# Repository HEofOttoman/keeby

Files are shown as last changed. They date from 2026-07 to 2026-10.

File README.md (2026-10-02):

<!-- # Kai-Board v1
Custom 65% compact keyboard made by I, Henry Wauzivuff. -->
<header align="center">
<h1>Kai-Board v1</h1>
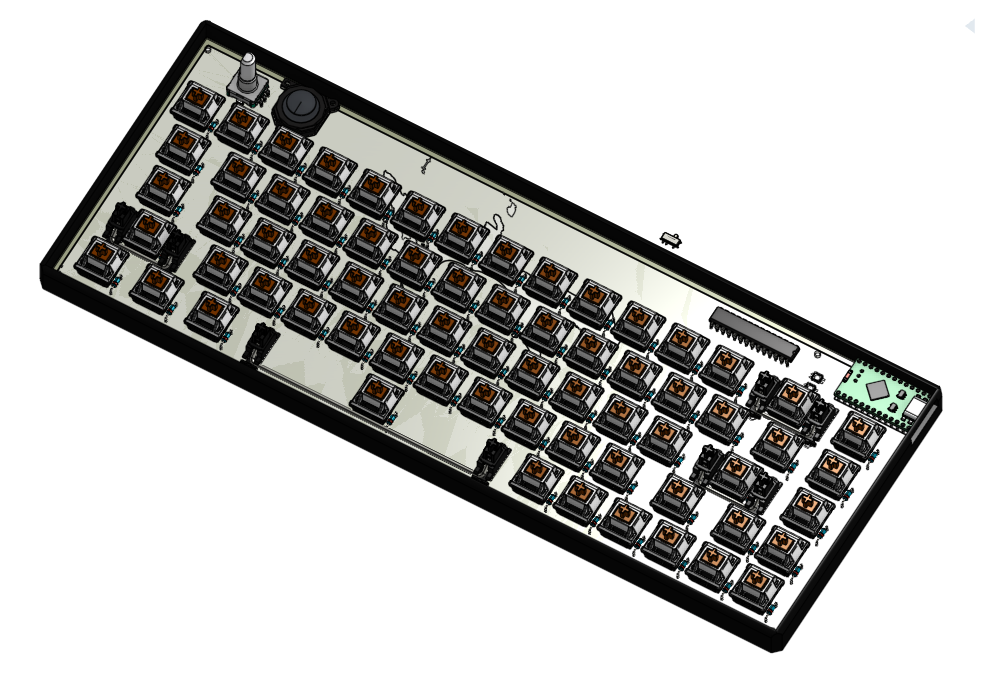
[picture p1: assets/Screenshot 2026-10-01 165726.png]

<h4>Custom wireless 65% compact keyboard made by Henry Wauzivuff.</h4>
</header>

## Features
- Wireless potential + Rechargable battery slot
- 65% compact
- Joystick (my replacement of the Thinkpad trackball)
- 1x EC11 Rotary Encoder

In a future design, I hope to include a usb hub, on/off switches, LEDs & whatever makes better use of the IO expander I ended up using

## Images

### Schematic
(outdated)

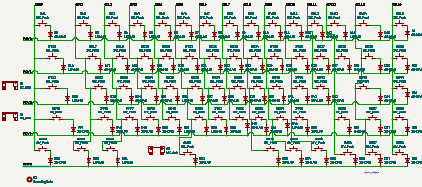
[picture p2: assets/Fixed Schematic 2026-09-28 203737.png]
and now, this works!!


### PCB
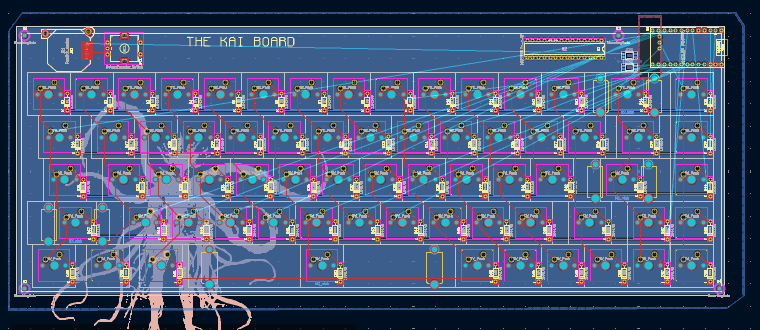
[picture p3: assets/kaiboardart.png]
art thing first


### CAD
Onshape link that may or may not [work](https://cad.onshape.com/documents/7e4f9e7530ad3774807d336c/w/6a2b4c794cd4ebe03f2424c9/e/2e40ded4774df0623cc9d47f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)
cad1

## BOM
|Qty|Item|Description|Cost (AUD/USD)|Link
|---|---|---|---|---|
|67x|MX Switches|Keys|||
|67x|1N4148|Diodes|||
|1x|Keycap Set|||
|1x|PCB||$$|
|1x|Case|housing duh|$|
|1x|PSP1000|Joystick maybe||
|2x|2.25u MX Stabilisers|||
|1x|6.25u MX Stabiliser|Spacebar|
|1x|2u MX Stabiliser|Backspace|
|1x|301230|Lipo Battery 500mAh|$2 (possible scam)|[aliexpress](https://www.aliexpress.com/item/32732458079.html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)|
|1x|MCP23017-SP GPIO Expanders||||

## References
Useful Links
- https://github.com/joric/nrfmicro/wiki
- https://github.com/RafaelCasamaximo/voidPointer
- https://github.com/ebastler/marbastlib (plugin & content manager)
- https://github.com/joric/nrfmicro/wiki/Pinout - Pinout, might be useful idk
- https://github.com/joric/nrfmicro/wiki/Alternatives/

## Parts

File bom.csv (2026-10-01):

Id | Designator | Footprint | Quantity | Designation | Supplier and ref
1 | D1, D2, D3, D4, D5, D6, D7, D8, D9, D10, D11, D12, D13, D14, D15, D16, D17, D18, D19, D20, D21, D22, D23, D24, D25, D26, D27, D28, D29, D30, D31, D32, D33, D34, D35, D36, D37, D38, D39, D40, D41, D42, D43, D44, D45, D46, D47, D48, D49, D50, D51, D52, D53, D54, D55, D56, D57, D58, D59, D60, D61, D62, D63, D64, D65, D66, D67, D68 | D_DO-35_SOD27_P7.62mm_Horizontal | 68 | 1N4148
2 | EC1 | ROT_Alps_EC11E-Switch | 1 | RotaryEncoder_Switch
3 | JS1 | PNT_psp1000 | 1 | joystick_analog
4 | LED1, LED2 | LED_SK6812MINI-E_3.2x2.8mm_P1.5mm_ReverseMount | 2 | SK6812MINI-E
5 | REF** | SW_MSK12C02-HB | 1 | SW_MSK12C02-HB
6 | S1, S3 | STAB_MX_2.25u | 2 | MX_stab
7 | S2 | STAB_MX_2u | 1 | MX_stab
8 | S4 | STAB_MX_6.25u | 1 | MX_stab
9 | SW1, SW2, SW3, SW4, SW5, SW6, SW7, SW8, SW9, SW10, SW11, SW12, SW13, SW14, SW15, SW16, SW17, SW18, SW19, SW20, SW21, SW22, SW23, SW24, SW25, SW26, SW27, SW28, SW29, SW30, SW31, SW32, SW33, SW34, SW35, SW36, SW37, SW38, SW39, SW40, SW41, SW42, SW43, SW44, SW45, SW46, SW47, SW48, SW49, SW50, SW51, SW52, SW53, SW54, SW55, SW56, SW57, SW58, SW59, SW60, SW61, SW62, SW63, SW64, SW65, SW66, SW67, SW68 | SW_MX_1u | 68 | SW_Push
10 | U2 | DIP-28_W7.62mm | 1 | MCP23017x-x-SP

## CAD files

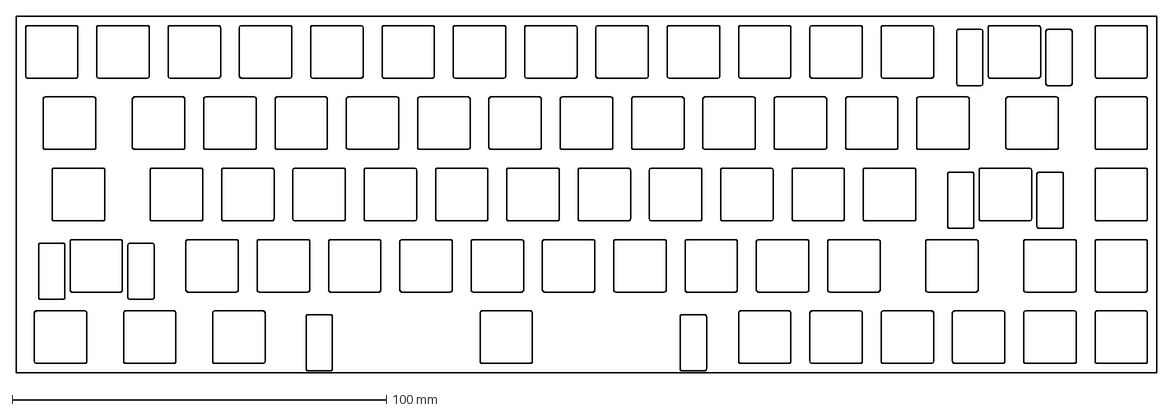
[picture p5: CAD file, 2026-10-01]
65%compact.dxf
304.8 x 95.2 mm

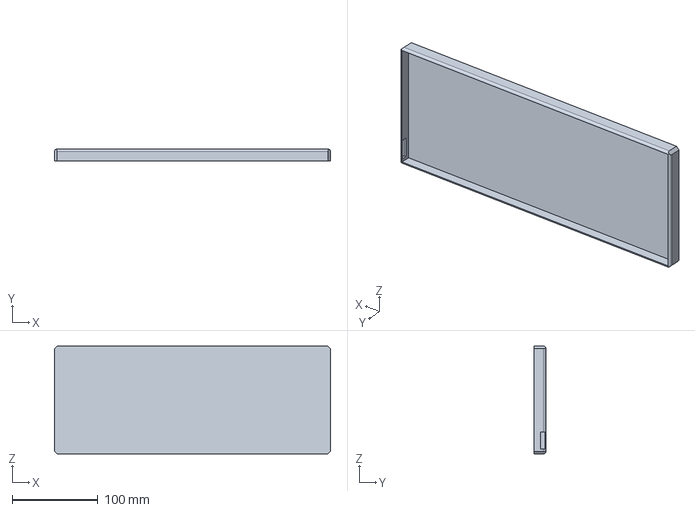
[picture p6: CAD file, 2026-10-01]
cad/Kai Board Case Base.step
321.0 x 13.5 x 125.5 mm

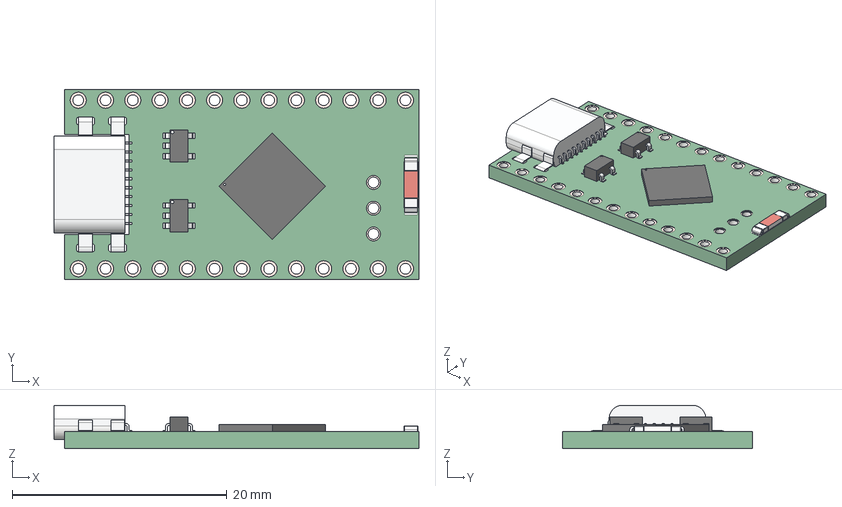
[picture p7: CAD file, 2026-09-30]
cad/nrf52840-1.snapshot.8/ProMicro NRF52840 AUYXSSZ.step
34.0 x 17.7 x 4.05 mm

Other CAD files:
cad/pcb v000.step
cad/nrf52840-1.snapshot.8/ProMicro NRF52840 AUYXSSZ.f3d

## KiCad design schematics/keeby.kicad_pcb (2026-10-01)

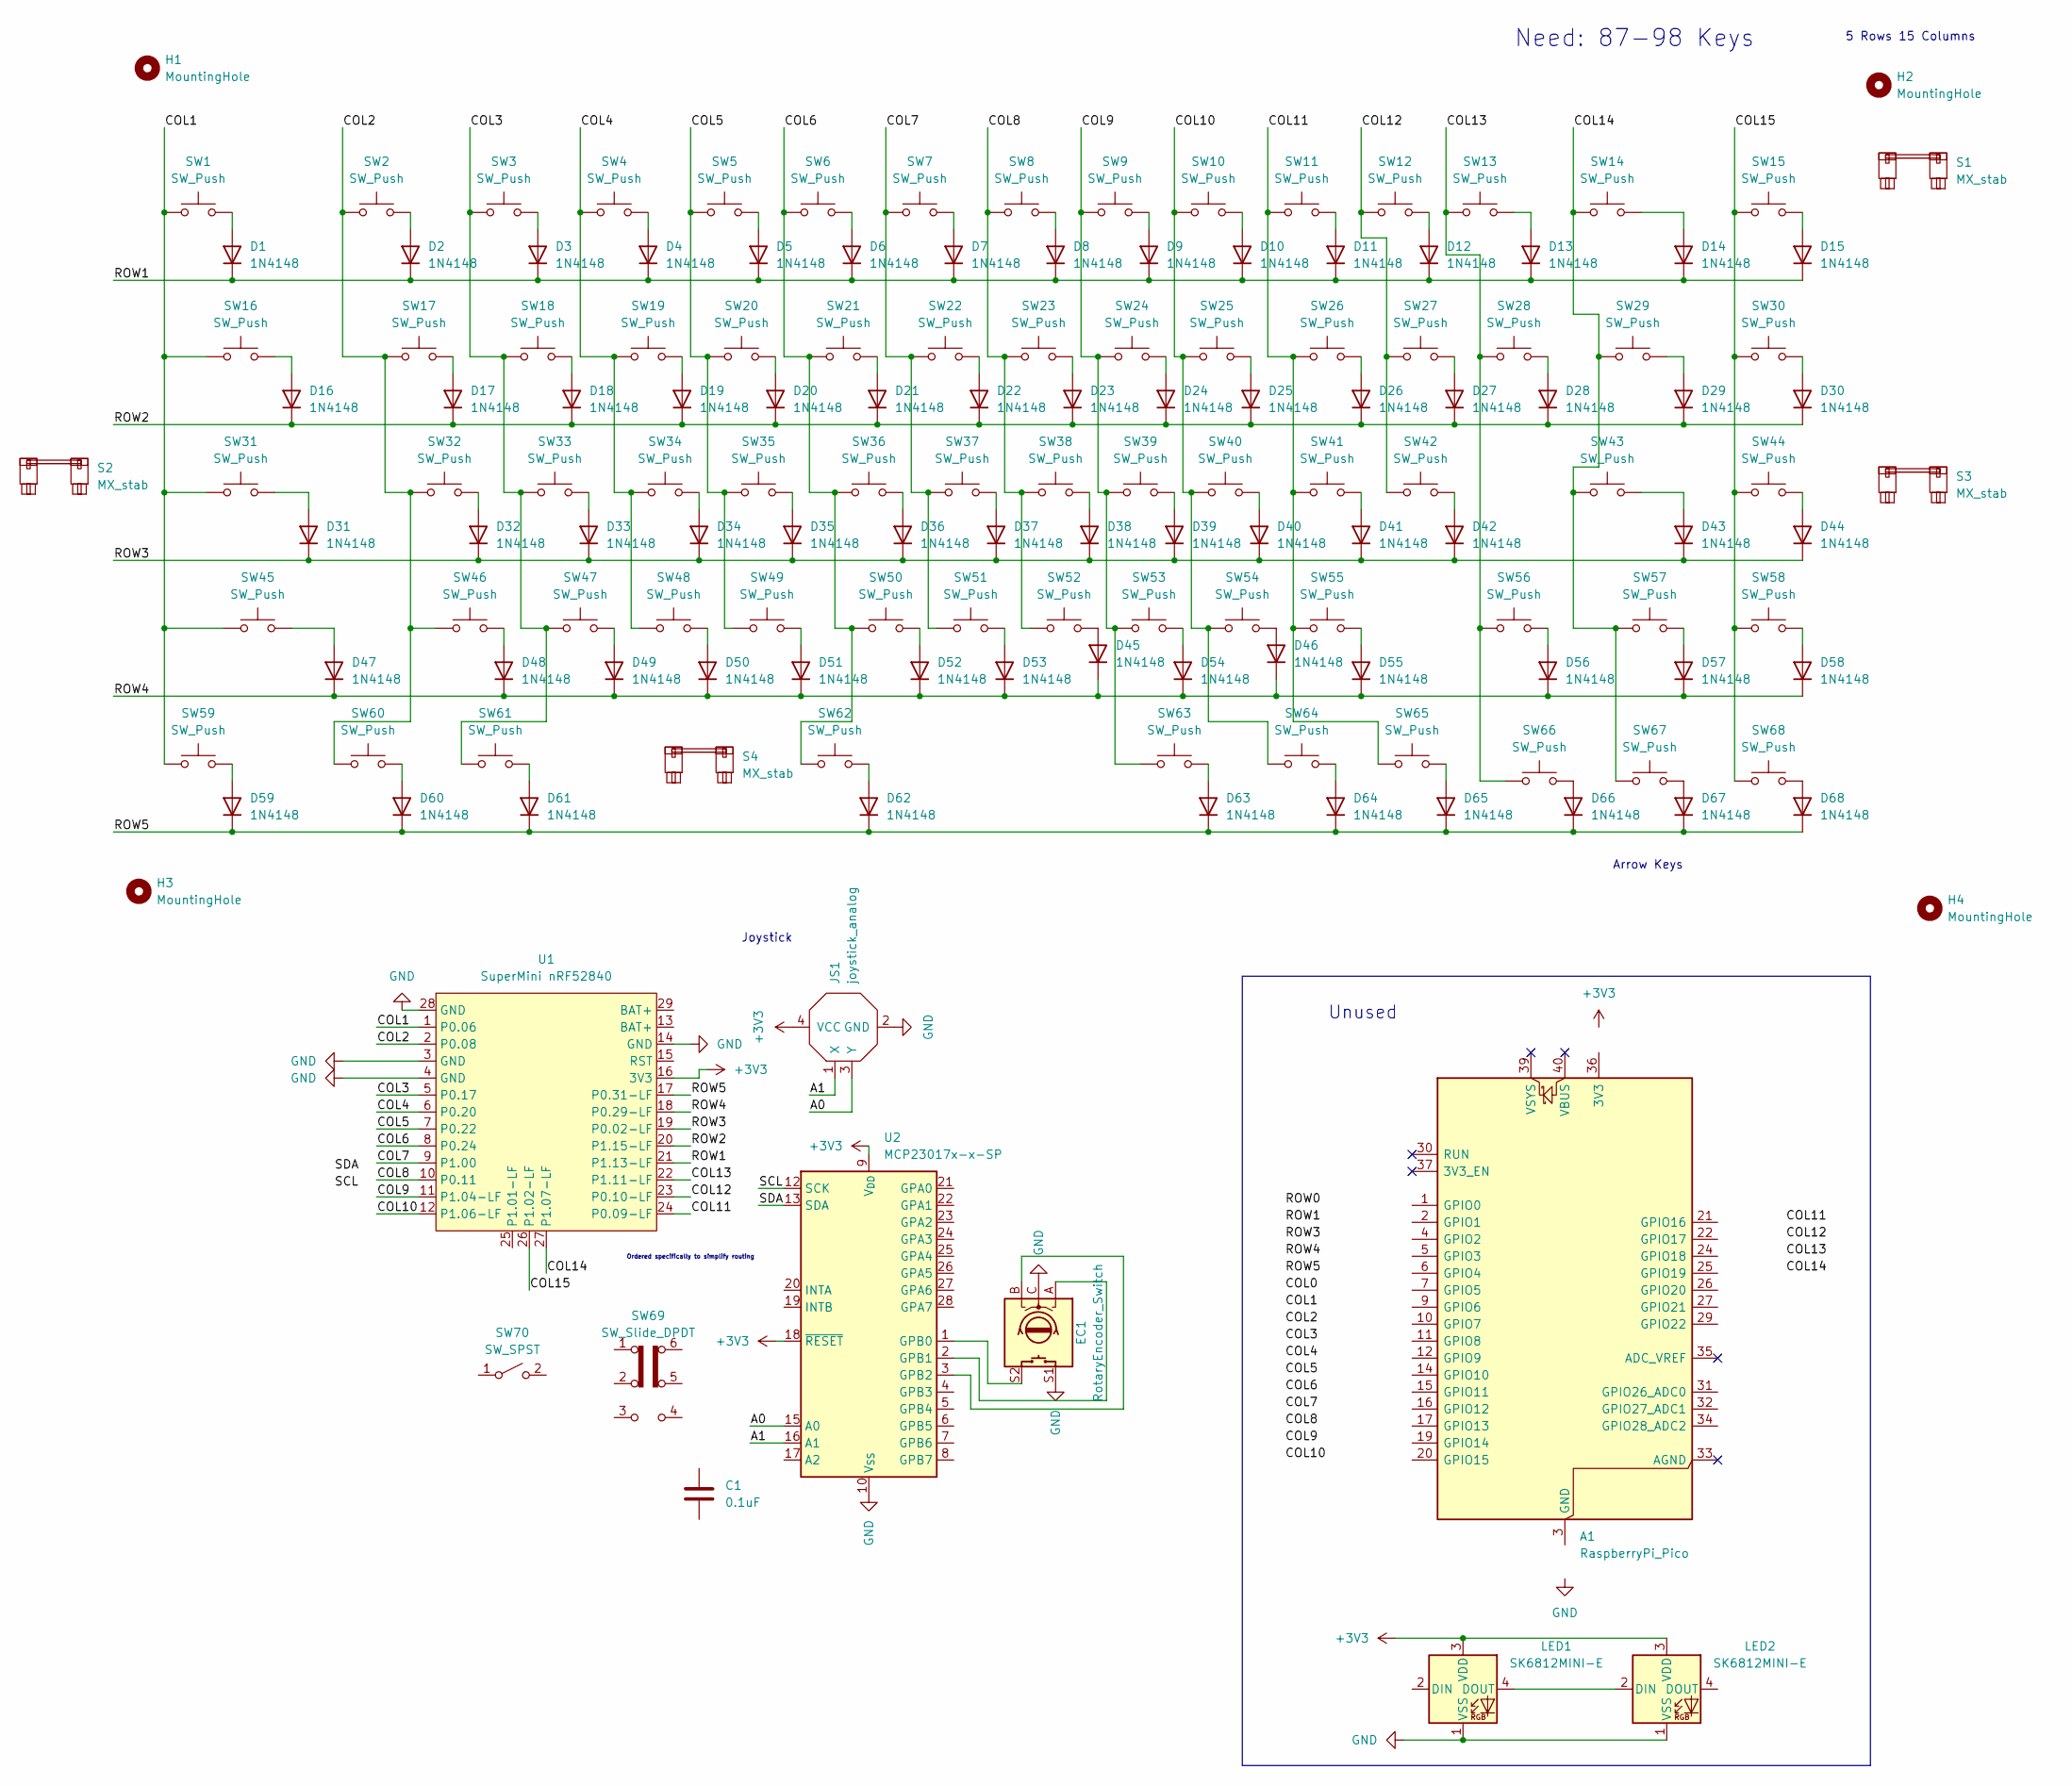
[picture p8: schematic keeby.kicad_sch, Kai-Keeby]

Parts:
A1: RaspberryPi_Pico; RaspberryPi_Pico_Common_THT
C1: 0.1uF
D1, D2, D3, D4, D5, D6, D7, D8, D9, D10, D11, D12, D13, D14, D15, D16, D17, D18, D19, D20, D21, D22, D23, D24, D25, D26, D27, D28, D29, D30, D31, D32, D33, D34, D35, D36, D37, D38, D39, D40, D41, D42, D43, D44, D45, D46, D47, D48, D49, D50, D51, D52, D53, D54, D55, D56, D57, D58, D59, D60, D61, D62, D63, D64, D65, D66, D67, D68: 1N4148; D_DO-35_SOD27_P7.62mm_Horizontal
EC1: RotaryEncoder_Switch; ROT_Alps_EC11E-Switch
H1, H2, H3, H4: MountingHole; MountingHole_2.2mm_M2
JS1: joystick_analog; PNT_psp1000
LED1, LED2: SK6812MINI-E; LED_SK6812MINI-E_3.2x2.8mm_P1.5mm_ReverseMount
S1, S3: MX_stab; STAB_MX_2.25u
S2: MX_stab; STAB_MX_2u
S4: MX_stab; STAB_MX_6.25u
SW1, SW2, SW3, SW4, SW5, SW6, SW7, SW8, SW9, SW10, SW11, SW12, SW13, SW14, SW15, SW16, SW17, SW18, SW19, SW20, SW21, SW22, SW23, SW24, SW25, SW26, SW27, SW28, SW29, SW30, SW31, SW32, SW33, SW34, SW35, SW36, SW37, SW38, SW39, SW40, SW41, SW42, SW43, SW44, SW45, SW46, SW47, SW48, SW49, SW50, SW51, SW52, SW53, SW54, SW55, SW56, SW57, SW58, SW59, SW60, SW61, SW62, SW63, SW64, SW65, SW66, SW67, SW68: SW_Push; SW_MX_1u
SW69: SW_Slide_DPDT
SW70: SW_SPST
U1: SuperMini nRF52840; SuperMini_nRF52840_AH_USBup
U2: MCP23017x-x-SP; DIP-28_W7.62mm

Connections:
+3V3: JS1.4 (VCC), LED1.3 (VDD), LED2.3 (VDD), U1.16 (3V3), U2.9 (V_{DD}), U2.18 (~RESET)
/A0: JS1.3 (Y), U2.15 (A0)
/A1: JS1.1 (X), U2.16 (A1)
/COL1: SW1.1, SW16.1, SW31.1, SW45.1, SW59.1, U1.1 (P0.06)
/COL2: SW2.1, SW17.1, SW32.1, SW46.1, SW60.1, U1.2 (P0.08)
/COL3: SW3.1, SW18.1, SW33.1, SW47.1, SW61.1, U1.5 (P0.17)
/COL4: SW4.1, SW19.1, SW34.1, SW48.1, U1.6 (P0.20)
/COL5: SW5.1, SW20.1, SW35.1, SW49.1, U1.7 (P0.22)
/COL6: SW6.1, SW21.1, SW36.1, SW50.1, SW62.1, U1.8 (P0.24)
/COL7: SW7.1, SW22.1, SW37.1, SW51.1, U1.9 (P1.00)
/COL8: SW8.1, SW23.1, SW38.1, SW52.1, U1.10 (P0.11)
/COL9: SW9.1, SW24.1, SW39.1, SW53.1, SW63.1, U1.11 (P1.04-LF)
/COL10: SW10.1, SW25.1, SW40.1, SW54.1, SW64.1, U1.12 (P1.06-LF)
/COL11: SW11.1, SW26.1, SW41.1, SW55.1, SW65.1, U1.24 (P0.09-LF)
/COL12: SW12.1, SW27.1, SW42.1, U1.23 (P0.10-LF)
/COL13: SW13.1, SW28.1, SW56.1, SW66.1, U1.22 (P1.11-LF)
/COL14: SW14.1, SW29.1, SW43.1, SW57.1, SW67.1, U1.27 (P1.07-LF)
/COL15: SW15.1, SW30.1, SW44.1, SW58.1, SW68.1, U1.26 (P1.02-LF)
/ROW1: D1.1 (K), D2.1 (K), D3.1 (K), D4.1 (K), D5.1 (K), D6.1 (K), D7.1 (K), D8.1 (K), D9.1 (K), D10.1 (K), D11.1 (K), D12.1 (K), D13.1 (K), D14.1 (K), D15.1 (K), U1.21 (P1.13-LF)
/ROW2: D16.1 (K), D17.1 (K), D18.1 (K), D19.1 (K), D20.1 (K), D21.1 (K), D22.1 (K), D23.1 (K), D24.1 (K), D25.1 (K), D26.1 (K), D27.1 (K), D28.1 (K), D29.1 (K), D30.1 (K), U1.20 (P1.15-LF)
/ROW3: D31.1 (K), D32.1 (K), D33.1 (K), D34.1 (K), D35.1 (K), D36.1 (K), D37.1 (K), D38.1 (K), D39.1 (K), D40.1 (K), D41.1 (K), D42.1 (K), D43.1 (K), D44.1 (K), U1.19 (P0.02-LF)
/ROW4: D45.1 (K), D46.1 (K), D47.1 (K), D48.1 (K), D49.1 (K), D50.1 (K), D51.1 (K), D52.1 (K), D53.1 (K), D54.1 (K), D55.1 (K), D56.1 (K), D57.1 (K), D58.1 (K), U1.18 (P0.29-LF)
/ROW5: D59.1 (K), D60.1 (K), D61.1 (K), D62.1 (K), D63.1 (K), D64.1 (K), D65.1 (K), D66.1 (K), D67.1 (K), D68.1 (K), U1.17 (P0.31-LF)
/SCL: U2.12 (SCK)
/SDA: U2.13 (SDA)
GND: EC1.C, EC1.S1, JS1.2 (GND), LED1.1 (VSS), LED2.1 (VSS), U1.3 (GND), U1.4 (GND), U1.14 (GND), U1.28 (GND), U2.10 (V_{SS})
unnamed: A1.3 (GND), A1.8 (GND), A1.13 (GND), A1.18 (GND), A1.23 (GND), A1.28 (GND), A1.38 (GND)
unnamed: D1.2 (A), SW1.2
unnamed: D2.2 (A), SW2.2
unnamed: D3.2 (A), SW3.2
unnamed: D4.2 (A), SW4.2
unnamed: D5.2 (A), SW5.2
unnamed: D6.2 (A), SW6.2
unnamed: D7.2 (A), SW7.2
unnamed: D8.2 (A), SW8.2
unnamed: D9.2 (A), SW9.2
unnamed: D10.2 (A), SW10.2
unnamed: D11.2 (A), SW11.2
unnamed: D12.2 (A), SW12.2
unnamed: D13.2 (A), SW13.2
unnamed: D14.2 (A), SW14.2
unnamed: D15.2 (A), SW15.2
unnamed: D16.2 (A), SW16.2
unnamed: D17.2 (A), SW17.2
unnamed: D18.2 (A), SW18.2
unnamed: D19.2 (A), SW19.2
unnamed: D20.2 (A), SW20.2
unnamed: D21.2 (A), SW21.2
unnamed: D22.2 (A), SW22.2
unnamed: D23.2 (A), SW23.2
unnamed: D24.2 (A), SW24.2
unnamed: D25.2 (A), SW25.2
unnamed: D26.2 (A), SW26.2
unnamed: D27.2 (A), SW27.2
unnamed: D28.2 (A), SW28.2
unnamed: D29.2 (A), SW29.2
unnamed: D30.2 (A), SW30.2
unnamed: D31.2 (A), SW31.2
unnamed: D32.2 (A), SW32.2
unnamed: D33.2 (A), SW33.2
unnamed: D34.2 (A), SW34.2
unnamed: D35.2 (A), SW35.2
unnamed: D36.2 (A), SW36.2
unnamed: D37.2 (A), SW37.2
unnamed: D38.2 (A), SW38.2
unnamed: D39.2 (A), SW39.2
unnamed: D40.2 (A), SW40.2
unnamed: D41.2 (A), SW41.2
unnamed: D42.2 (A), SW42.2
unnamed: D43.2 (A), SW43.2
unnamed: D44.2 (A), SW44.2
unnamed: D45.2 (A), SW52.2
unnamed: D46.2 (A), SW54.2
unnamed: D47.2 (A), SW45.2
unnamed: D48.2 (A), SW46.2
unnamed: D49.2 (A), SW47.2
unnamed: D50.2 (A), SW48.2
unnamed: D51.2 (A), SW49.2
unnamed: D52.2 (A), SW50.2
unnamed: D53.2 (A), SW51.2
unnamed: D54.2 (A), SW53.2
unnamed: D55.2 (A), SW55.2
unnamed: D56.2 (A), SW56.2
unnamed: D57.2 (A), SW57.2
unnamed: D58.2 (A), SW58.2
unnamed: D59.2 (A), SW59.2
unnamed: D60.2 (A), SW60.2
unnamed: D61.2 (A), SW61.2
unnamed: D62.2 (A), SW62.2
unnamed: D63.2 (A), SW63.2
unnamed: D64.2 (A), SW64.2
unnamed: D65.2 (A), SW65.2
unnamed: D66.2 (A), SW66.2
unnamed: D67.2 (A), SW67.2
unnamed: D68.2 (A), SW68.2
unnamed: LED1.4 (DOUT), LED2.2 (DIN)
unnamed: EC1.S2, U2.1 (GPB0)
unnamed: EC1.A, U2.2 (GPB1)
unnamed: EC1.B, U2.3 (GPB2)

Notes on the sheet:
Ordered specifically to simplify routing
Arrow Keys
Joystick
Need: 87-98 Keys
Unused
5 Rows 15 Columns

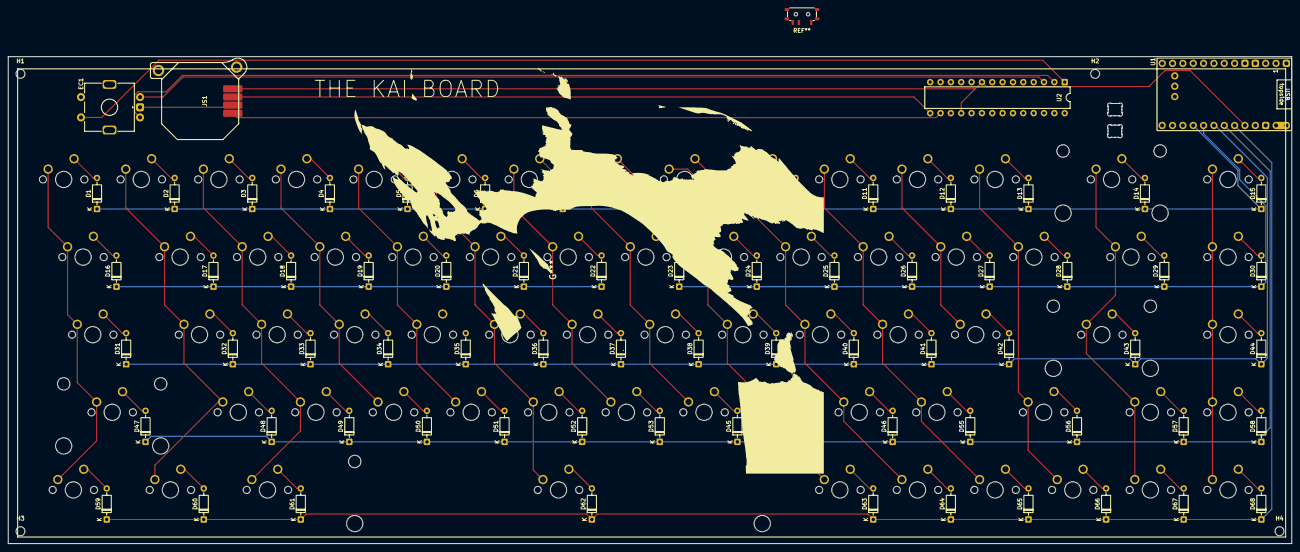
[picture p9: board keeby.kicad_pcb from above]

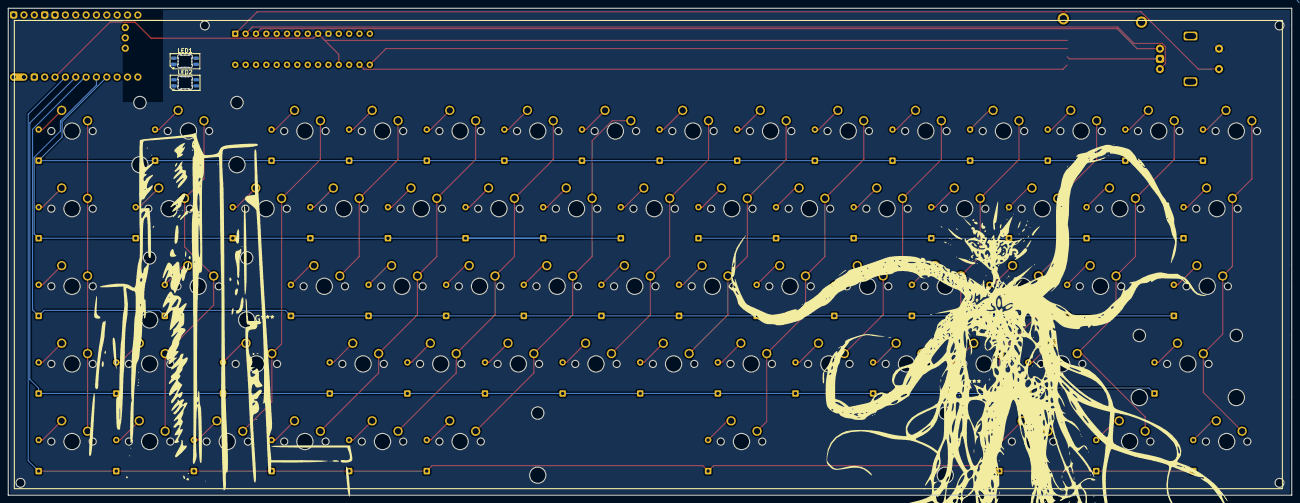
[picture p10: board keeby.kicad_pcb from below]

Board: 2 copper layers, 315.0 x 119.5 mm, 150 parts (2 on the bottom side), 96 nets.

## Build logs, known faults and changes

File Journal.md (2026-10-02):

# First Journal!
|Name|Kai Board|
|---|---|
|Author|Henry W|
|Total Hours|~15+|

## 21-22 July 26 - ~1-1.5hr
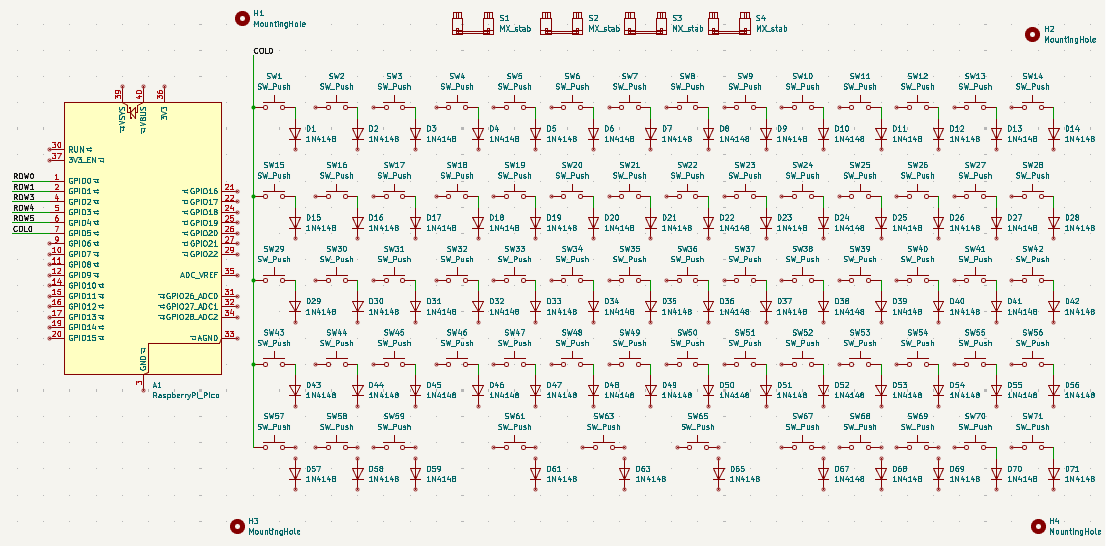
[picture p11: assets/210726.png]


I have begun writing this journal. Installed marbastlib. Don't have a plan for my design yet, should probably think about that soon. Put down the basics of the schematic I think I'll use. Some labels here and there. Drawing schematics is just so satisfying, yk?

The next day I worked on the columns more. Tried the first import to the pcb.
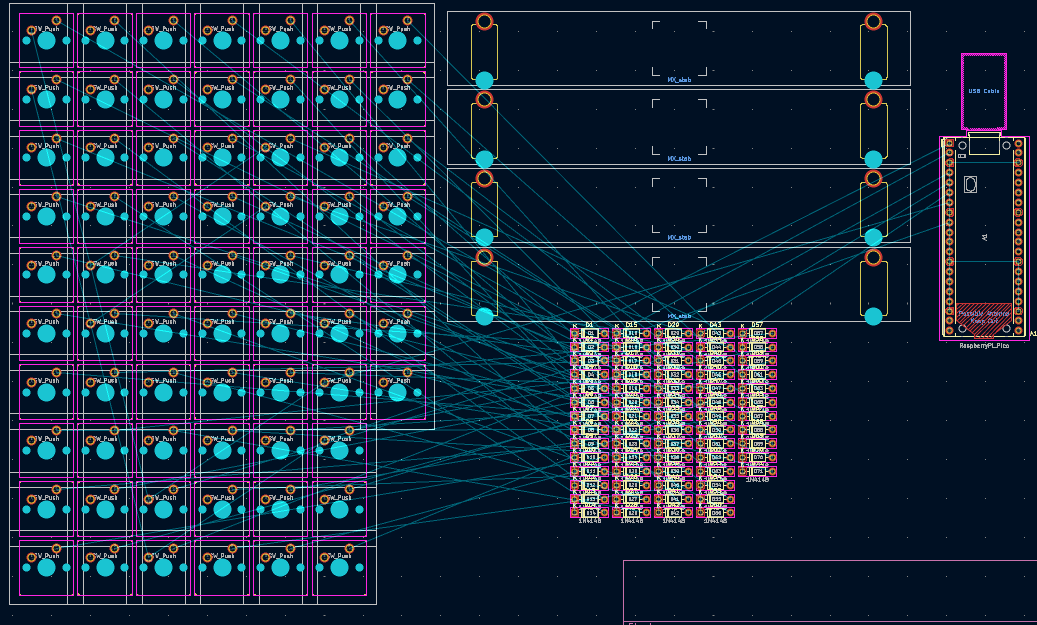
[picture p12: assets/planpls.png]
i should get a plan


## 1 September 26 ~2.5hrs
Oh boy, it's been a while. Keeb's ending in a 30 days so I should really get cracking! I've been going back to the drawing board, since I probably really need to figure out a layout before going anywhere else at this stage. I opened a new document in Krita for hardware ideas, which is probably bad for efficiency and other methods exist, but idk. I like the compact design of [this keyboard by Tap](https://hackclub.slack.com/archives/C0ATP7MTNPJ/p1784718798722599) specifically because of the way the arrow keys are compacted with the rest of the layout. 

From my design ideas, the calculations have yielded ***87(75%)-98(96%)*** keys layedout compactly! I think that's all I need to know to start working on my PCB!

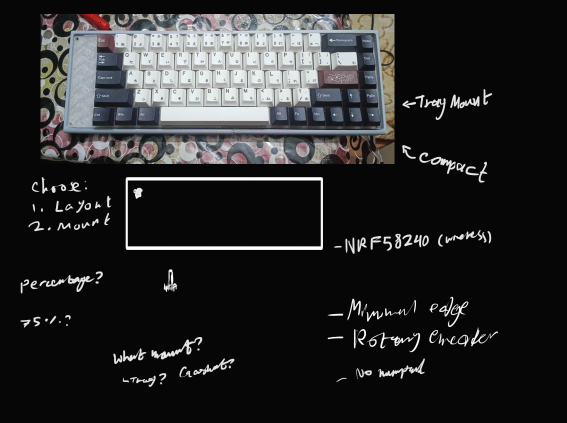
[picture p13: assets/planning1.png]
planning 1
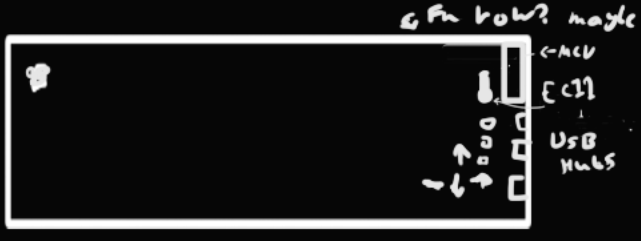
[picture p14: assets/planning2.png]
planning 2


One of the things I also thought about (but didn't really need to at this stage come to think about it) was [keyboard mounting styles](https://www.monsgeek.com/blog/comprehensive-guide-to-keyboard-mounting-styles/).

- OH yeah also I wanted to add a USB hub like Geg-Tech's one.
- YES! 19.05/8mm grid is important.
- NRF52840

## 2 September 26 5hrs
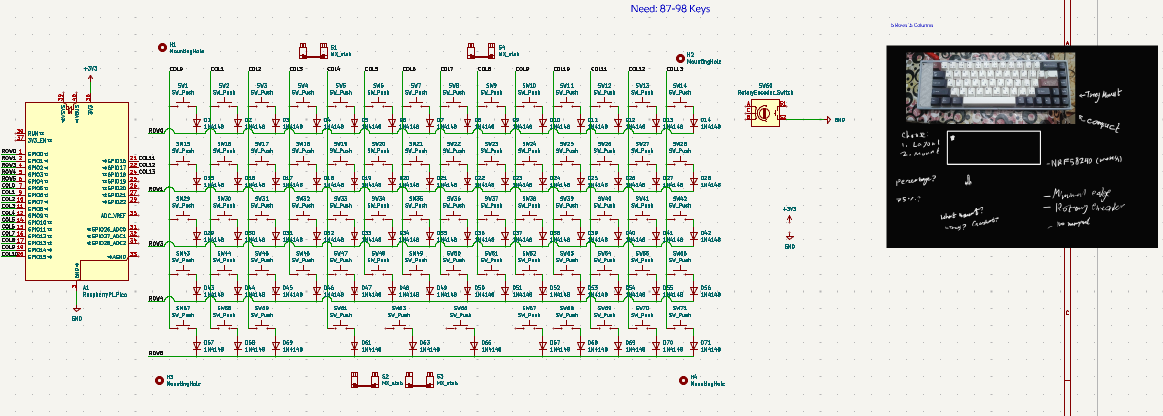
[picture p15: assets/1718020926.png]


Continued assigning rows/columns. Moved to reassigning things, my head hurts a LOT. The switches look nice and all layed out, but the key layout is different to what it should be. VERY MUCH SO.

I started using KBplacer somewhere this time here

## 28 September 26 4hrs
From last time I worked on this keyboard, I figured out I needed to delete an entire column, that being column 15.

This is giving me a headache. I am close though. Only like 1 key away from this layout is correct.
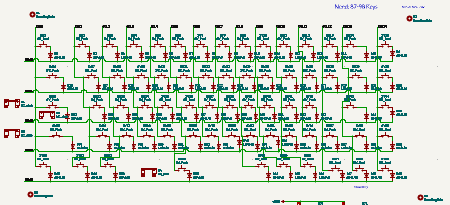
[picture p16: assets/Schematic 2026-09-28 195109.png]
almost there

I think I narrowed it down to SW56 in that image
And now, this works!! Much less messy and now, this works!!

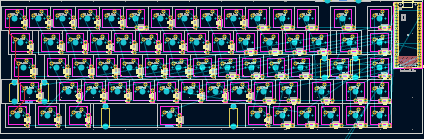
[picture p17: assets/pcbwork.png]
pcb


I proceeded to spend a long time rotating the diodes. Then rotating. Then routing.

It was here I realised that I realised I connect col_13 to the pi twice :praying:

I came across a weird issue where my keyboard edge cuts is completely busted. 

## 29 September 26 ~4hrs
I then realised it was because of a miniscule edge.cuts object.

From Kbplacer's placement that was mostly correct, there was a problem with the placement of the switches..
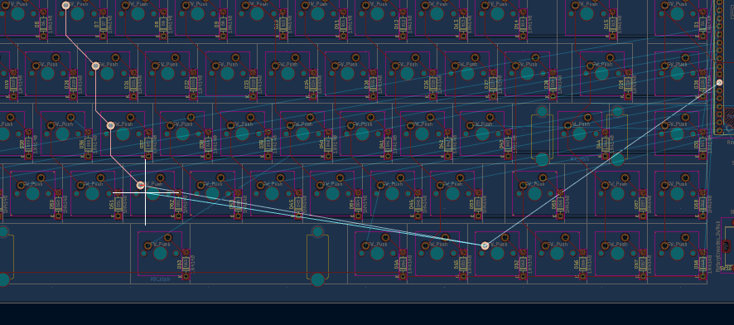
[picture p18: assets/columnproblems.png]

Now I start writing down parts for the BOM because why not. I have 67 keys and diodes. 

It is about this time I probably decide against using an LED to reduce battery usage.

I am using 301230 (301230 means 3.0 x 12 x 30 mm) Li-Po batteries, because they sit flush and fit snugly between two 4.5mm tall machine pin sockets (per [this guy](https://github.com/joric/nrfmicro/wiki/)).

Annotate schematic being a lil silly and putting components out of wack. 

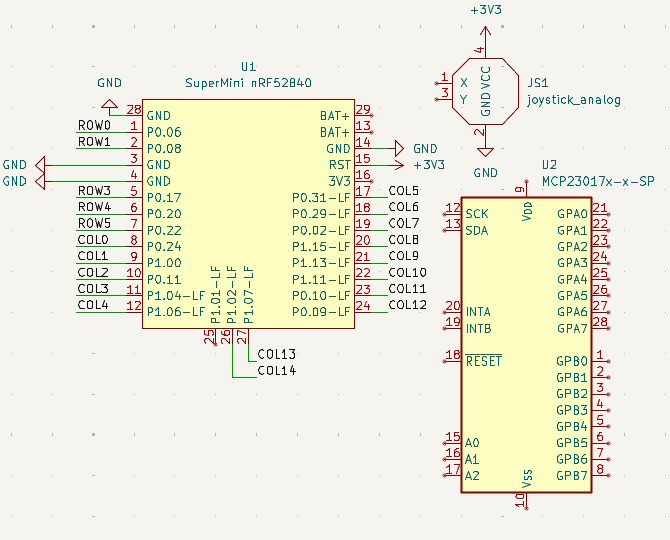
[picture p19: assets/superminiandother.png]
new parts?


I started looking for a pinout to the Supermini to help me wire the nrf to the gpio 
https://github.com/pdcook/nRFMicro-Arduino-Core The locations of the Bat+ & Bat- pins are something I need to look out for

This, is where I come across a design dilemma. The Supermini has the exact amount of pins I need for my keyboard matrix, but one extra pin & nothing else; I can't add the other things I wanted: not the LEDs, the rotary encoder, nor the joystick.

I could also resize the board, but I can't move onto cad from there. 
I could then work on the firmware instead, but I still don't know if I want to use ZMK as opposed to RMK because rust is coolio

30 September 2026 5Hrs
---
*Keeb ends in less than a day... I must lock in.*

I proceeded to spend time assigning 3d models to each of these switches and all the stabilisers. I then added the mounting holes. 

Cue trying to start firmware on the side.

I also decided to move the mcu from the side to the top.

It is here that I then realise I somehow mislabeled the rows so that it's ROW0, ROW1, then straight to ROW3. I hope trying to fix this doesn't break anything...

I have decided on the board dimensions of 119.5 x 315 mm

Now I rearrange pins on the board to simplify routing

I then also added some art
keyboard art

Now, to connect the IO expander. SDA & SCL are the two pins I need, but the pinouts for the nrf52840 supermini featuring SDA/SCL seems to be inconsistent..
one pinout and another i found
Apparently the SDA/SCL pins for the nrf52840 is defined in the firmware, something something duplex matrix. I'm still unsure though, this is a massive risk if I wire it wrong so I should probably get the supermini devboards to test first before the pcb. Fingers crossed you're right gorkie

## 1 October 2026 - 4.5 hours
I decided to switch & shift the positions of the joystick & EC11, so it feels more 'natural' in my own imagination, though it makes the EC11 much harder to wire (being that it points to the other side). I am doing some messy routing, finally wiring the MCP23017 correctly to the ie. VSS/GND VDD/3.3v. 

Anyway it's almost 30 September 11:59PM EST, I should REALLY get to finishing it up.
I then exported a quick bom from KiCad, the PCB one. I speedran a case, still not my best work. The pcb still needs a bit of routing and shifting around to make it all efficient.

Case Render

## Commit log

2026-07-21 made kicad proj
    [keeby.kicad_pcb, keeby.kicad_sch]
2026-07-22 journaling + more schematic
    [keeby.kicad_sch]
2026-07-22 hjalp vro
    [keeby.kicad_pcb, keeby.kicad_sch]
2026-09-02 15 columns and 5 rows
    [keeby.kicad_sch]
2026-09-03 laid out this ratnest is hurting my brain
    installed kbplacer to do ts
    [keeby.kicad_pcb, keeby.kicad_sch]
2026-09-28 I have narrowed down the headache of all the keys. I can route peacefully now.
    +maybe some uncommitted changes from a few days ago as well...
    [keeby.kicad_pcb, keeby.kicad_sch]
2026-09-29 more hours of work
    [keeby.kicad_pcb, keeby.kicad_sch]
2026-09-29 checkpointer. readme stuff. more journal. fix switch order
    [keeby.kicad_pcb, keeby.kicad_sch]
2026-09-29 connected the nrf to the column/rows.
    [keeby.kicad_pcb, keeby.kicad_sch]
2026-09-30 added nrf 3d models and all the other needed models
    models and nrf
    the commit before had a few things merged together that I actually wanted to separate into different commits
    [ProMicro NRF52840 AUYXSSZ.f3d, ProMicro NRF52840 AUYXSSZ.step, keeby.kicad_pcb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]
2026-09-30 ZMK CLI is a bum so I manually added a bunch of files based on what google ai thinks is the default
    also the rows in the schematic are out of order
    - Pls google ai not be a bum
    [keeby.kicad_pcb]
2026-10-01 a bunch of messy routing and wiring
    [keeby.kicad_pcb, keeby.kicad_sch]
2026-10-01 pcb export 1 but im gonna change it anyway
    help im going to shift the microcontroller up a bit
    [keeby.kicad_pcb, keeby.kicad_sch, pcb v000.step]
2026-10-01 hi i am adding some things to make it mildly shippable in this state
    unignored some things from gitignore.
    almost leaked my username whoops
    [65%compact.dxf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]
2026-10-01 things that don't get me discombobulated by 1mon
    - journaled
    - cad base
    - bom (unignored duped line in gitignore lol)
    - readme update
    [Kai Board Case Base.step, bom.csv]
2026-10-01 removed dupe
    [keeby-B_Cu.gbr, keeby-B_Mask.gbr, keeby-B_Paste.gbr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]
